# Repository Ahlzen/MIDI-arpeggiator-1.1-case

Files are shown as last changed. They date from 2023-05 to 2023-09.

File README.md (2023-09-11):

# MIDI-arpeggiator-1.1-case
Case and panel artwork for MIDI Arpeggiator v1.1

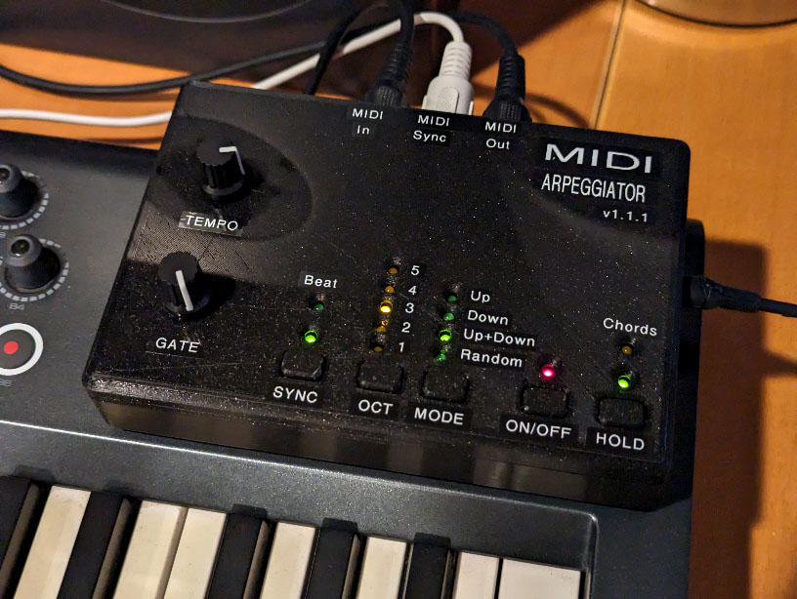
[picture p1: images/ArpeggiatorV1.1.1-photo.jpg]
Photo of case


## Case parts

These parts are created with OpenSCAD (source included) and are designed to be 3D-printed.

Adjust parameters in *common.scad* to adjust size, positions, case thickness, rounding, etc.

* *case-bottom.scad* and *case-top.scad* are meant to be printed face down.
* *button.scad* creates a complete set of panel buttons connected by thin flexible strings (so they stay aligned)
* *knob.scad* TODO.

## Print

Print the top, bottom and button strip face down. No supports required.

Inside holes have a tendency to shrink on FDM prints. If the holes (for screws or buttons) are too small, diameters and clearances can be adjusted in common.scad.

Knob (cap) for the potentiometers is not included (yet) but you can use something like this (also my designs!):

https://www.thingiverse.com/thing:4807288

or

https://www.thingiverse.com/thing:4828448

Both of the above can be customized, and will work with knurled or D-shaft potentiometers.

## Assembly

A total of 10 self tapping screws are required - 6 for the PCB standoffs, and 4 on the sides of the case. [#4 x 3/8 sheet metal screws](https://www.boltdepot.com/Product-Details.aspx?product=5436) work well.

If using other screws, adjust the hole diameter in *common.scad*. Rule of thumb is to make the hole size about the same diameter
as the major diameter of the screw (outside of the thread) - then the pull/shrinkage during print is usually enough for the thread to grab into.

## License

TODO

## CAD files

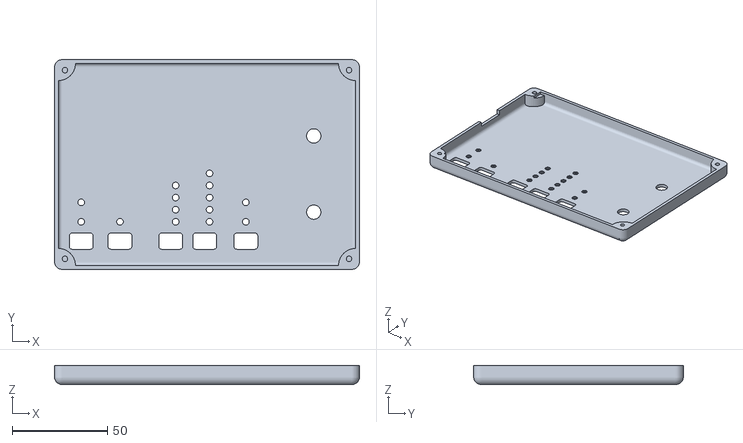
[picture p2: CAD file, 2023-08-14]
stl/case-top.stl
160.0 x 110.0 x 10.0

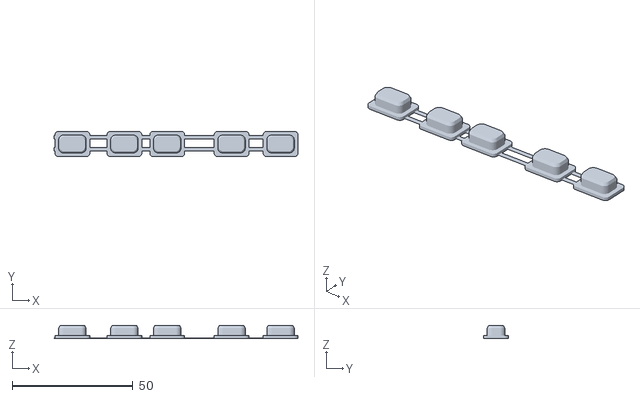
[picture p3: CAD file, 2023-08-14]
stl/buttons.stl
101.2 x 10.5 x 5.20

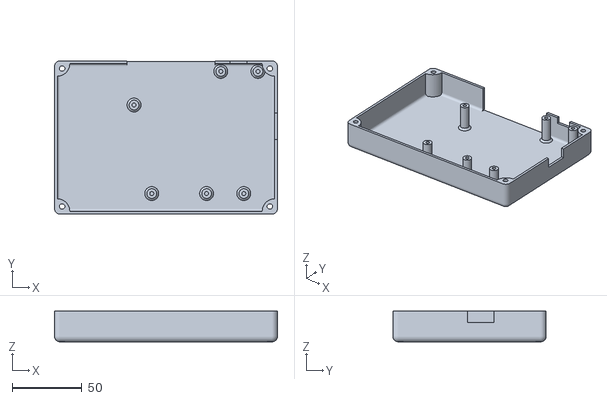
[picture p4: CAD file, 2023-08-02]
stl/case-bottom.stl
160.0 x 110.0 x 22.0

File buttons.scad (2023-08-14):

include <MCAD/boxes.scad>
include <common.scad>

$fn = $preview ? 15 : 40;

topHeight = 2+thickness;
minBottomHeight = 1.2;
bottomHeight = max(minBottomHeight, pcbToCeiling - switchHeight - 0.5);
totalHeight = topHeight + bottomHeight;
//cutoutDepth = - (pcbToCeiling - switchHeight - 0.8); // last term compensates for sagging in bridging

module button() {
  hull() {
    translate([0,0,topHeight/2-0.5])
      roundedBox([buttonX-buttonClearance, buttonY-buttonClearance, topHeight-1], 2, true);
    translate([0,0,topHeight/2])
      roundedBox([buttonX-buttonClearance-1, buttonY-buttonClearance-1, topHeight], 2, true);
  }
  translate([0,0,-bottomHeight/2])
    roundedBox([buttonX+2, buttonY+2, bottomHeight], buttonR, true);
}
/*
module zigZagString(length, segmentLength, width, thickness)
  linear_extrude(thickness)
    for (n = [0 : length/segmentLength])
      translate([(n+.5)*segmentLength,0])
        rotate([0,0,n % 2 == 0 ? 45 : -45])
          square([segmentLength*sqrt(2)+width, width], center=true);
*/
//zigZagString(100, 5, 1, 0.2);


difference() {
  
  union() {
    // string (to keep spacing)    
    translate([0,2,-bottomHeight])
      cube([buttonCoords[len(buttonCoords)-1].x, 1.6, 0.2]);
      //zigZagString(buttonCoords[len(buttonCoords)-1].x, 2, 1.2, 0.2);
    translate([0,-3,-bottomHeight])
      cube([buttonCoords[len(buttonCoords)-1].x, 1.6, 0.2]);
    //zigZagString(buttonCoords[len(buttonCoords)-1].x, 2, 1.2, 0.2);
    

    // buttons
    for (buttonCoord = buttonCoords)
      translate([buttonCoord.x, 0, 0])
        button();
  };
  // Cutouts to allow enough clearance for pushbuttons on PCB,
  // if needed
  /*
  for (buttonCoord = buttonCoords)
    translate([buttonCoord.x, 0, -bottomHeight+cutoutDepth/2-e])
      //roundedBox([pcbSwitchX, pcbSwitchY, cutoutDepth], 1, true);  
      cube([pcbSwitchX+1, pcbSwitchY+1, cutoutDepth], center=true);  
  */
}

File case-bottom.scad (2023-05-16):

include <MCAD/boxes.scad>
include <common.scad>

$fn = $preview ? 15 : 40;

module standoff(x, y) {
  translate([pcbOX+x, pcbOY+pcbY-y, thickness-e]) {
    cylinder(h=1.5, d1=standoffOD+3, d2=standoffOD); // fillet
    difference() {
      cylinder(h=bottomZ-thickness, d=standoffOD);
      cylinder(h=bottomZ, d=standoffID); // hole
}}}

difference() {
  case();
  // Cut off flat top
  translate([0,0,bottomZ])
    cube([caseX, caseY, caseZ]);  
  
  // Back cutouts
  for (i = [0:len(backCutouts)-1]) {
    cutout = backCutouts[i];
    x = pcbOX+cutout[0];
    w = cutout[1]-cutout[0];
    h = cutout[2];
    translate([x, pcbOY+pcbY-caseR, pcbOZ-h])
      cube([w, 100, h]);
  }
  
  // Right side cutouts
  for (i = [0:len(sideCutouts)-1]) {
    cutout = sideCutouts[i];
    y = pcbOY+pcbY-cutout[1];
    w = cutout[1]-cutout[0];
    h = cutout[2];
    translate([pcbOX+pcbX, y, pcbOZ-h])
      cube([100, w, h]);
  }
}

// Standoffs
// NOTE: y-coordinate is inverted since KiCAD uses top left as origin
for (i = [0:len(holeCoords)-1])
  standoff(holeCoords[i].x, holeCoords[i].y);

// PCB (uncomment to view)
//pcb();

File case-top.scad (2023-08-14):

include <MCAD/boxes.scad>
include <common.scad>

$fn = $preview ? 15 : 40;

module button(x,y) {
  translate([pcbOX+x, pcbOY+pcbY-y, 0]) {
    roundedBox([buttonX, buttonY, 100], buttonR, true);
}}

module led(x,y) {
  translate([pcbOX+x, pcbOY+pcbY-y, pcbZ+pcbToCeiling-e]) {
    // flare LED hole slightly for better viewing angle if not
    // flush with surface
    cylinder(d=ledD, h=10);
    translate([0,0,0.4]) cylinder(d1=ledD, d2=ledD+14, h=10);
}}


// turn it upside down so it's automatically oriented for 3d printing
rotate([0,180,0])

difference() {
  translate([0,0,-bottomZ])
    case();
  // Cut off flat bottom
  translate([0,0,-caseZ])
    cube([caseX, caseY, caseZ]);
  // Right side cutouts
  for (i = [0:len(sideCutouts)-1]) {
    cutout = sideCutouts[i];
    y = pcbOY+pcbY-cutout[1];
    w = cutout[1]-cutout[0];
    h = cutout[3];
    translate([pcbOX+pcbX, y, 0])
      cube([100, w, h]);
  }
  // Holes for buttons and LEDs
  for (i = [0:len(buttonCoords)-1])
    button(buttonCoords[i].x, buttonCoords[i].y);
  for (i = [0:len(ledCoords)-1])
    led(ledCoords[i].x, ledCoords[i].y);
  // Holes for potentiometers
  for (i = [0:len(potCoords)-1])
    translate([potCoords[i].x, potCoords[i].y, 0])
      cylinder(d=potD, h=100);
}

// PCB (uncomment to view)
//translate([0,0,-bottomZ]) pcb();

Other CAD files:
common.scad

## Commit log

2023-04-19 Initial commit.
    [case-bottom.scad, case-top.scad, common.scad]
2023-04-19 Created basic button cap.
    [button.scad, case-top.scad, common.scad]
2023-04-19 Created connected string of spaced out button caps.
    [button.scad]
2023-04-19 Increased resolution for non-preview render.
    [button.scad, case-bottom.scad, case-top.scad]
2023-04-29 Tweaked case dimensions after better measurements.
    [button.scad, common.scad]
2023-05-07 Updated assembly instructions.
2023-05-08 Minor tweaks to dimensions.
    [case-bottom.scad, common.scad]
2023-05-11 Slightly flared LED holes (for better viewing angle)
    [case-top.scad]
2023-05-16 Changed from mounting tabs to corner screws.
    [case-bottom.scad, case-top.scad, common.scad]
2023-05-16 Moved PCB closer to right edge.
    [case-bottom.scad, case-top.scad, common.scad]
2023-05-31 Updated buttons for adjusted case thickness.
    [button.scad, buttons.scad, common.scad]
2023-05-31 Added STLs
    [buttons.stl, case-bottom.stl, case-top.stl]
2023-08-02 Minor tweaks to top panel.
    [case-bottom.stl, case-top.scad, case-top.stl]
2023-08-05 Fixed error in buttons.scad. Updated STLs.
    [buttons.scad, buttons.stl, case-top.stl]
2023-08-06 More tweaks to buttons.
    [buttons.scad, common.scad]
2023-08-07 Further minor tweaks to zig-zag strings that keep buttons together.
    [buttons.scad, buttons.stl]
2023-08-08 Increased default button clearance. Increased button cutout depth.
    [buttons.scad, buttons.stl, common.scad]
2023-08-14 More tweaks to case-top and buttons.
    [buttons.scad, buttons.stl, case-top.scad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]
2023-09-11 Added photo of case.
2023-09-11 Update README.md
    Added case photo to README,md
